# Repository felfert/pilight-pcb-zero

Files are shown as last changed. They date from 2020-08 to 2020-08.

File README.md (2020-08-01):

# pilight-pcb-zero

A minimalistic pcb for connecting a receiver and transmitter for pilight to a Raspberry PI Zero WH.

Parts:

- PCB: See e.g.: https://aisler.net/p/JOIFAOLQ
- Aurel RX-4M50RR30SF: See e.g.: https://www.amazon.de/s?k=RX-4M50RR30SF
- NoName China TX 433Mhz: https://www.amazon.de/Anpro-Empf%C3%A4nger-Superregeneration-Transmitter-Einbrecher/dp/B071J2Z3YK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 (Throw away the receivers, those are crap)
- 13x2 PIN Socket: See e.g.: https://www.reichelt.de/2x13pol-buchsenl-gerade-rm-2-54-h-8-5mm-bl-2x13g8-2-54-p51834.html
- 4x2 PIN Socket: See e.g.: https://www.reichelt.de/rnd-stiftleiste-8-pol-rm-2-54-mm-rnd-205-00635-p208861.html?&nbc=1
- R1, R3, R4, R5: 1k
- R2: 1M potentiometer: See e.g.: https://www.reichelt.de/spindeltrimmer-25-gaenge-1-mohm-linear-vis-m64y105kb40-p238621.html?&nbc=1
- 2 Antennas: See e.g.: https://www.amazon.de/gp/product/B07FYX7WBW/ref=ppx_yo_dt_b_asin_title_o06_s00

Notes:

 - J1 is placed on the opposite side of the PCB
 - The second Antenna cable is connected directly to the TX-Module.
 - There is a sqare solder mask for GND of the RX-Antenna on the HAT PCB near U2.

 J2 and the corresponding R3 - R5 implement the following optional additional features

   Power button
   Power LED
   Wifi LED
   TX LED

   For these, additional scripts resp. configuration is required which can be found in the custom/ subdir.

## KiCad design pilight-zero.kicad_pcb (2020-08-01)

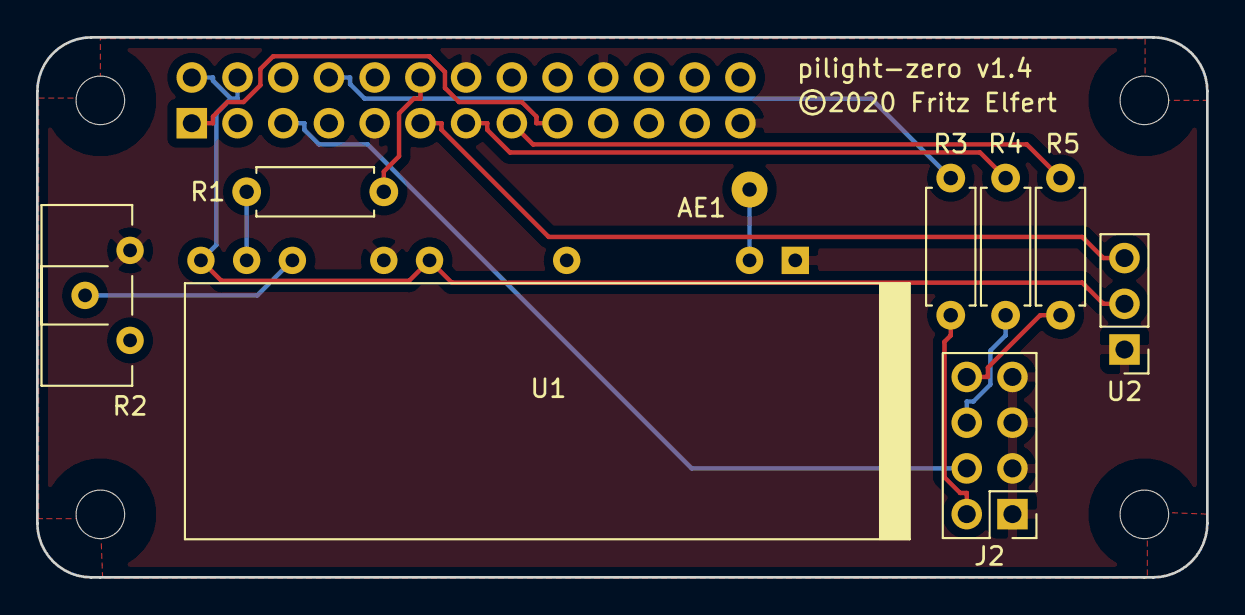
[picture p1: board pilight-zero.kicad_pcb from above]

Board: 2 copper layers, 65.0 x 30.0 mm, 14 parts (1 on the bottom side), 15 nets.

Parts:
AE1: Antenna; SolderWirePad_1x01_Drill0.8mm
H1, H2, H3, H4: MountingHole; MountingHole_2.7mm_M2.5_uHAT_RPi
J1: GPIO partial; PinSocket_2x13_P2.54mm_Vertical_Special_Anchor
J2: Conn_02x04_Odd_Even; PinHeader_2x04_P2.54mm_Vertical
R1, R3, R4, R5: 1k; R_Axial_DIN0207_L6.3mm_D2.5mm_P7.62mm_Horizontal
R2: 1M; Potentiometer_ACP_CA9-H2,5_Horizontal
U1: RX-4M50RR30SF
U2: TX_433Mhz; TX-433Mhz

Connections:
+3V3: J1.1, J1.17
+5V: J1.2, J1.4, U1.10, U1.15, U2.2
/GPIO3_SCL1: J1.5, J2.4
/GPIO14_TXD0: J1.8, R3.1
/GPIO17_GEN0: J1.11, U2.3
/GPIO18_GEN1: J1.12, R1.2
/GPIO22_GEN3: J1.15, R5.1
/GPIO27_GEN2: J1.13, R4.1
/PwrLED: J2.2, R3.2
/TxLED: J2.8, R5.2
/WifiLED: J2.6, R4.2
GND: J1.6, J1.9, J1.14, J1.20, J1.25, J2.1, J2.3, J2.5, J2.7, R2.3, U1.2, U1.7, U1.11, U2.1
unnamed: AE1.1, U1.3
unnamed: R1.1, U1.14
unnamed: R2.2, U1.13

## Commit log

2020-06-21 Initial import
    [pilight-zero.kicad_pcb, pilight-zero.sch]
2020-06-21 Add Note about Antenna 2
2020-06-21 Replaced R2 by pot
    [pilight-zero.kicad_pcb, pilight-zero.sch]
2020-06-21 Add 3D model for trimmer
    [pilight-zero.kicad_pcb, pilight-zero.sch]
2020-07-31 Misc fixes and additions
    - Fixed pad dimensions of potentiometer
    - Added pinheader and resistors for
    - Power button
    - Power LED
    - Wifi LED
    - 433Mhz TX LED
    [pilight-zero.kicad_pcb, pilight-zero.sch]
2020-08-01 Updated misc 3d models
    [pilight-zero.kicad_pcb, pilight-zero.sch]
2020-08-01 Changed WifiLED output to GPIO27
    [pilight-zero.kicad_pcb, pilight-zero.sch]
2020-08-01 Bumped silk version number
    [pilight-zero.kicad_pcb]

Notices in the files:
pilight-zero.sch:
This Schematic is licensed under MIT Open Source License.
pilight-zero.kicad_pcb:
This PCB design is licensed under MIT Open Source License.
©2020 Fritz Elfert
